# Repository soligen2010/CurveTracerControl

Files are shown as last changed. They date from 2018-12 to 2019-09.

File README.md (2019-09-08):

# CurveTracerControl

 This program is intended to instrument the Curve Tracer design published by Mr. Carlson's Lab on Patreon.  The original MCL
 design is available only to Patreon subscribers.  This software is released Open Source but does not contain the original 
 MCL project information upon which it is built.  If you want to build this project, I suggest you join Mr. Carlson's Lab on 
 Patreon to get the original project that this program augments.

 This project adds the following functionality to the MCL Curve Tracer

 1) Frequency counter for the Sine Wave
 2) Peak sine wave voltage display
 3) Step generator with hi/lo voltage display

 The step generator uses an R2R ladder and is fed through a series of op amps.  A Potentiometer controls final amplitude 
 and an op amp inverts the steps so that negative steps can be used.  A switch selects resistors to limit output current 
 to 10, 100, or 1000 uA. See the schematic for more details.
 
 This program uses a 5 volt 16 MHz Arduino with an ATMEGA328P.  Use of any other hardware may require alterations to the code. 
 A crystal oscillator rather than a resonator is preferred for frequency counter accuracy.

 The frequency counter in this program is limited to low frequencies.  It works for frequencies up to ~1000 Hz, but will
 likely fail at 2000 Hz or before.  The tested frequency range is 30 to 1070 Hz.
 
 Requires the NewLiquidCrystal Library from https://github.com/fmalpartida/New-LiquidCrystal
 
 Copyright 2018 by Dennis Cabell
 KE8FZX

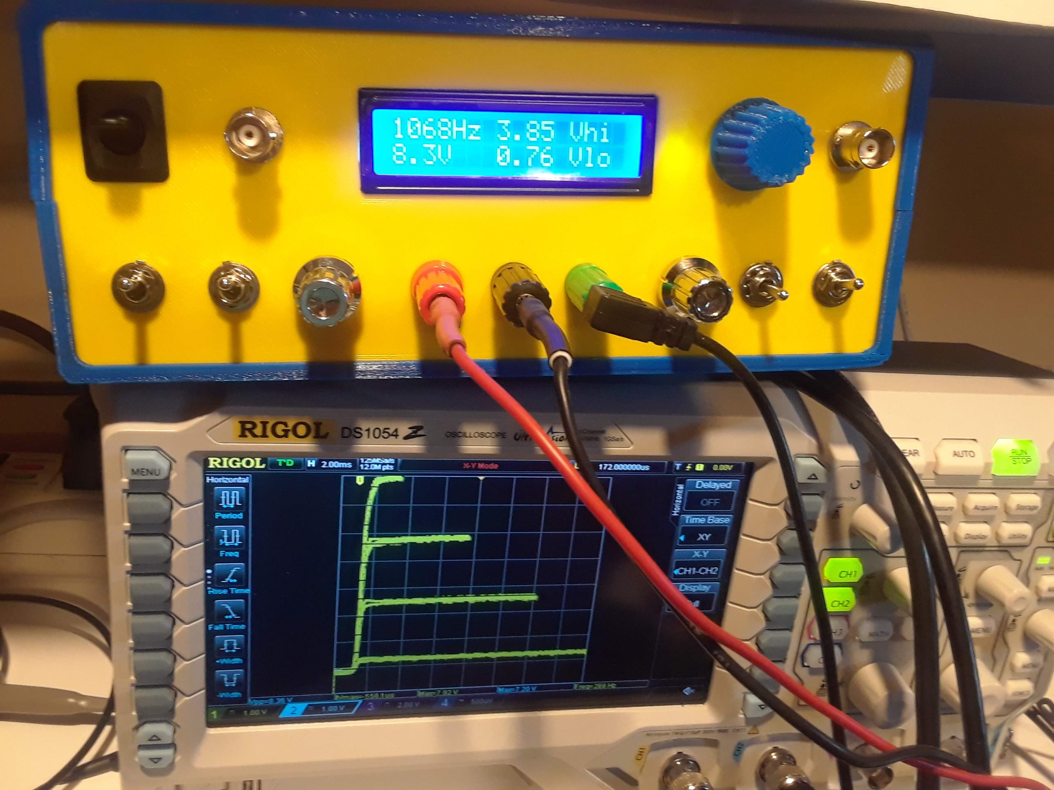
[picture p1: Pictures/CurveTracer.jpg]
Stepes Curves in Operation

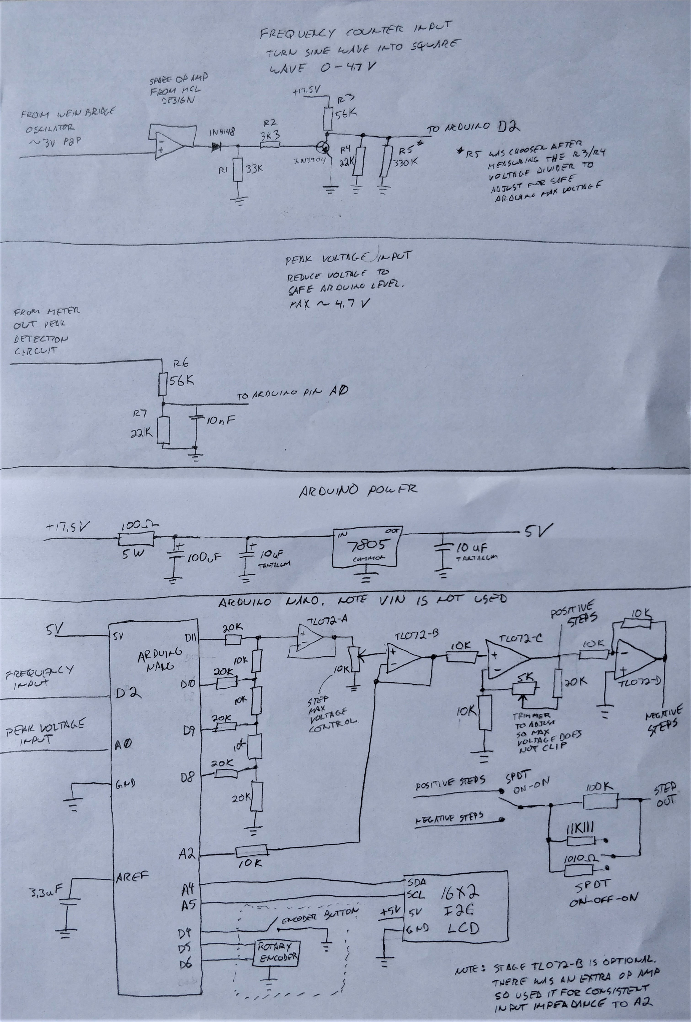
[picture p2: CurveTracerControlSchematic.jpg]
Schematic


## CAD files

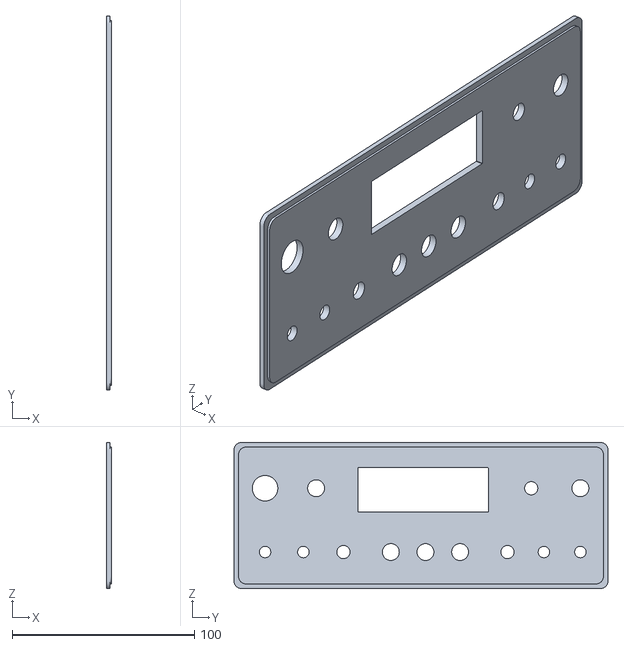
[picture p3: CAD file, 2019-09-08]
Case/CurveTracerFrontThick.stl
3.00 x 205.1 x 80.1

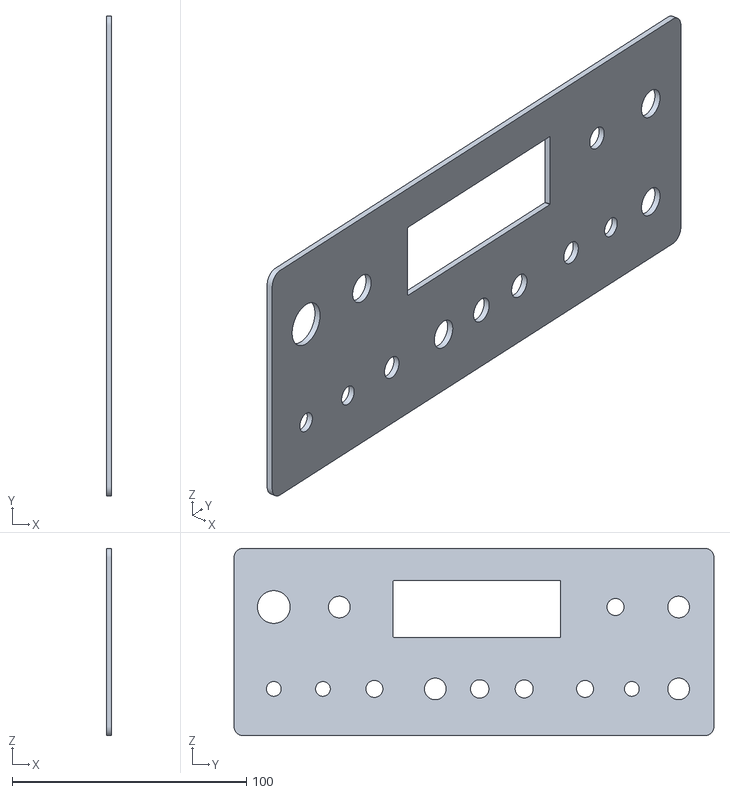
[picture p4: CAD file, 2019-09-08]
Case/CurveTracerFront.stl
2.00 x 205.1 x 80.1

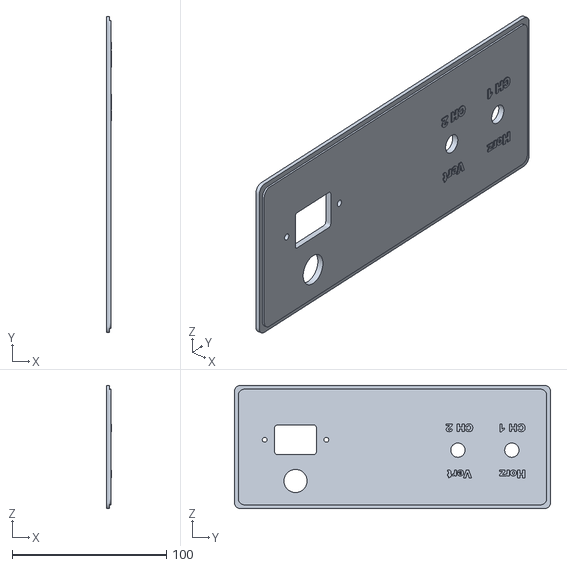
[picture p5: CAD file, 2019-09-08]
Case/CurveTracerBackThick.stl
3.50 x 205.1 x 80.1

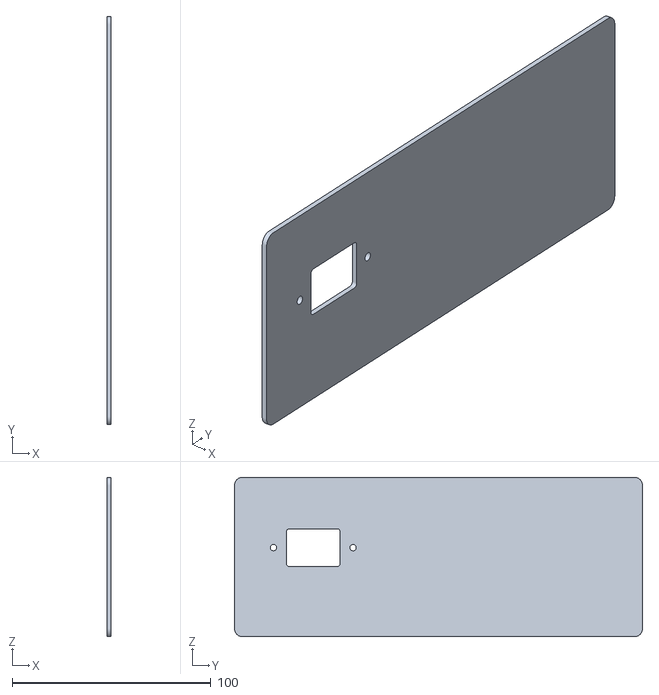
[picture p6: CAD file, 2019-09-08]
Case/CurveTracerBack.stl
2.00 x 205.1 x 80.1

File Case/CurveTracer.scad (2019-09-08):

/*//////////////////////////////////////////////////////////////////
              -    FB Aka Heartman/Hearty 2016     -                   
              -   http://heartygfx.blogspot.com    -                  
              -       OpenScad Parametric Box      -                     
              -         CC BY-NC 3.0 License       -                      
////////////////////////////////////////////////////////////////////                                                                                                             
12/02/2016 - Fixed minor bug 
28/02/2016 - Added holes ventilation option                    
09/03/2016 - Added PCB feet support, fixed the shell artefact on export mode. 
21/11/2017 by Richard Pillay - Added ability to have up to 4 PCBs

*/////////////////////////// - Info - //////////////////////////////

// All coordinates are starting as integrated circuit pins.
// From the top view :

//   CoordD           <---       CoordC
//                                 ^
//                                 ^
//                                 ^
//   CoordA           --->       CoordB


////////////////////////////////////////////////////////////////////


////////// - Paramètres de la boite - Box parameters - /////////////

/* [Box dimensions] */
// - Longueur - Length  
  Length        = 135;       
// - Largeur - Width
  Width         = 210;                     
// - Hauteur - Height  
  Height        = 85;  
// - Epaisseur - Wall thickness  
  Thick         = 2;//[2:5]  
// - Extra Panel Thickness - Double thickness (except edge) 
// usefull if panel contains a difficult plug
  ThickPanels   = 1;// 0 or 1
/* [Box options] */
// - Diamètre Coin arrondi - Filet diameter  
  Filet         = 4;//[0.1:12] 
// - lissage de l'arrondi - Filet smoothness  
  Resolution    = 50;//[1:100] 
// - Tolérance - Tolerance (Panel/rails gap)
  m             = 0.9;
// Pieds PCB - PCB feet (x4 for each) 
  PCB01Feet       = 0;// [0:No, 1:Yes]
  PCB02Feet       = 0;// [0:No, 1:Yes]
  PCB03Feet       = 0;// [0:No, 1:Yes]
  PCB04Feet       = 0;// [0:No, 1:Yes]
// - Decorations to ventilation holes
  Vent          = 1;// [0:No, 1:Yes]
// - Decoration-Holes width (in mm)
      Vent_width    = 1.5;   


  
/* [PCB_Feet] */
//All dimensions are from the center foot axis

PCB01Text = "PSU";
// - Coin bas gauche - Low left corner X position
PCB01PosX         = 10;
// - Coin bas gauche - Low left corner Y position
PCB01PosY         = 4;
// - Longueur PCB01 - PCB01 Length
PCB01Length       = 75;
// - Largeur PCB01 - PCB01 Width
PCB01Width        = 55;
// - Heuteur pied - Feet height
PCB01FootHeight      = 10;
// - Diamètre pied - Foot diameter
PCB01FootDiam         = 8;
// - Diamètre trou - Hole diameter
PCB01FootHole        = 2;  

PCB02Text = "Main";
PCB02PosX           = 10;
PCB02PosY           = 73;
PCB02Length         = 75;
PCB02Width          = 115;
PCB02FootHeight     = 10;
PCB02FootDiam      = 8;
PCB02FootHole        = 2;  
  
PCB03Text = "Regulator";
PCB03PosX           = 70;
PCB03PosY         = 110;
PCB03Length       = 50;
PCB03Width        = 55;
PCB03FootHeight      = 15;
PCB03FootDiam         = 10;
PCB03FootHole        = 3;  
  
PCB04Text = "FanMount";
PCB04PosX         = 25;
PCB04PosY         = 33;
PCB04Length       = 105;
PCB04Width        = 105;
    PCB04FootHeight      = 5;
PCB04FootDiam         = 12;
PCB04FootHole        = 5;  
  

/* [STL element to export] */
//Coque haut - Top shell
TShell          = 0;// [0:No, 1:Yes]
//Coque bas- Bottom shell
BShell          = 0;// [0:No, 1:Yes]
//Panneau avant - Front panel
FPanL           = 1;// [0:No, 1:Yes]
//Panneau arrière - Back panel  
BPanL           = 0;// [0:No, 1:Yes]


  
/* [Hidden] */
// - Couleur coque - Shell color  
Couleur1        = "Orange";       
// - Couleur panneaux - Panels color    
Couleur2        = "OrangeRed";    
// Thick X 2 - making decorations thicker if it is a vent to make sure they go through shell
Dec_Thick       = Vent ? Thick*2 : Thick; 
// - Depth decoration
Dec_size        = Vent ? Thick*2 : 0.8;





/////////// - Boitier générique bord arrondis - Generic rounded box - //////////

module RoundBox($a=Length, $b=Width, $c=Height){// Cube bords arrondis
                    $fn=Resolution;            
                    translate([0,Filet,Filet]){  
                    minkowski (){                                              
                        cube ([$a-(Length/2),$b-(2*Filet),$c-(2*Filet)], center = false);
                        rotate([0,90,0]){    
                        cylinder(r=Filet,h=Length/2, center = false);
                            } 
                        }
                    }
                }// End of RoundBox Module

      
////////////////////////////////// - Module Coque/Shell - //////////////////////////////////         

module Coque(){//Coque - Shell  
    Thick = Thick*2;  
    difference(){    
        difference(){//sides decoration
            union(){    
                     difference() {//soustraction de la forme centrale - Substraction Fileted box
                      
                        difference(){//soustraction cube median - Median cube slicer
                            union() {//union               
                            difference(){//Coque    
                                RoundBox();
                                translate([Thick/2,Thick/2,Thick/2]){     
                                        RoundBox($a=Length-Thick, $b=Width-Thick, $c=Height-Thick);
                                        }
                                        }//Fin diff Coque                            
                                difference(){//largeur Rails        
                                     translate([Thick+m,Thick/2,Thick/2]){// Rails
                                          RoundBox($a=Length-((2*Thick)+(2*m)), $b=Width-Thick, $c=Height-(Thick*2));
                                                          }//fin Rails
                                     translate([((Thick+m/2)*1.55),Thick/2,Thick/2+0.1]){ // +0.1 added to avoid the artefact
                                          RoundBox($a=Length-((Thick*3)+2*m), $b=Width-Thick, $c=Height-Thick);
                                                    }           
                                                }//Fin largeur Rails
                                    }//Fin union                                   
                               translate([-Thick,-Thick,Height/2]){// Cube à soustraire
                                    cube ([Length+100, Width+100, Height], center=false);
                                            }                                            
                                      }//fin soustraction cube median - End Median cube slicer
                               translate([-Thick/2,Thick,Thick]){// Forme de soustraction centrale 
                                    RoundBox($a=Length+Thick, $b=Width-Thick*2, $c=Height-Thick);       
                                    }                          
                                }                                          


                difference(){// wall fixation box legs
                    union(){
                        translate([3*Thick +5,Thick,Height/2]){
                            rotate([90,0,0]){
                                    $fn=6;
                                    cylinder(d=16,Thick/2);
                                    }   
                            }
                            
                       translate([Length-((3*Thick)+5),Thick,Height/2]){
                            rotate([90,0,0]){
                                    $fn=6;
                                    cylinder(d=16,Thick/2);
                                    }   
                            }

                        }
                            translate([4,Thick+Filet,Height/2-57]){   
                             rotate([45,0,0]){
                                   cube([Length,40,40]);    
                                  }
                           }
                           translate([0,-(Thick*1.46),Height/2]){
                                cube([Length,Thick*2,10]);
                           }
                    } //Fin fixation box legs
            }

        union(){// outbox sides decorations
            
            for(i=[0:Thick:Length/4]){
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

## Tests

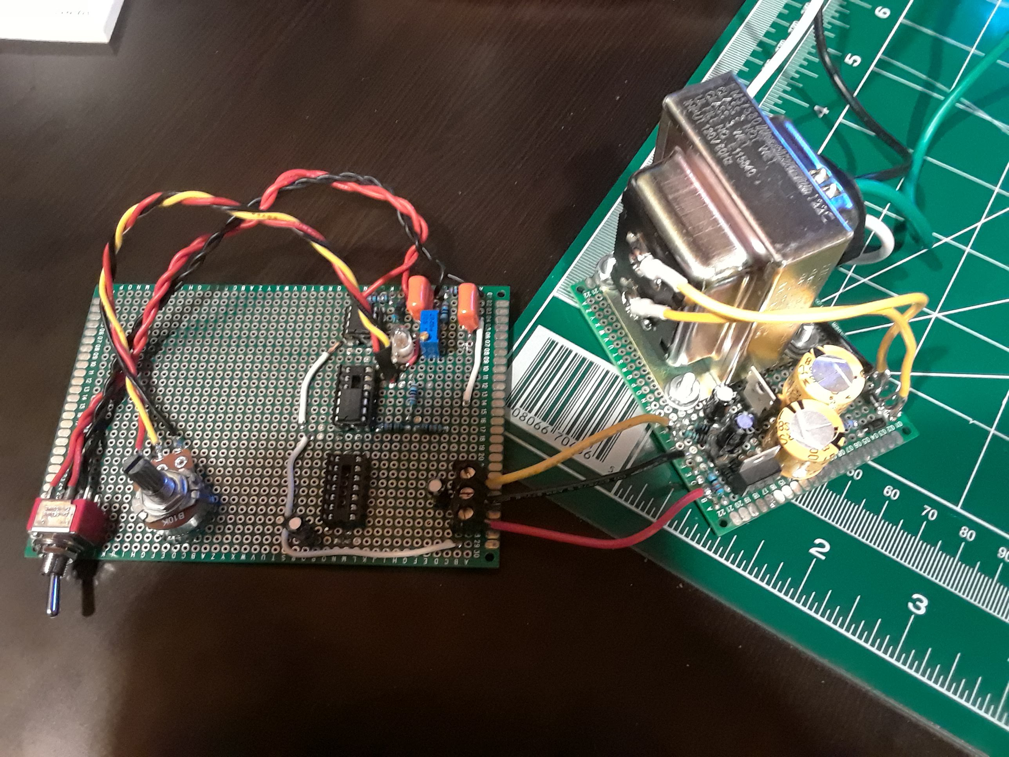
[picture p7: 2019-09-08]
Pictures/PartiallyComplete-Testing.jpg

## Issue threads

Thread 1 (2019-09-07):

Cannot upload the code

ovi4, 2019-09-07:
Hi, I am a contributor to Mr Carlson's Lab (on Patreon) and have access to all of his releases including the Curve Tracer schematic diagram and so on. Well I've already built the above Curve tracer and wanted to apply Denis Cambell's digital MOD  to it and already made a board with all the necessary (according to the given schematic but when tried to upload your code to my arduino uno board I get the following errors :

CurveTracerControl:92:15: error: expected primary-expression before 'encoder2'
 RotaryEncoder encoder2(ENCODER_PINB, ENCODER_PINA);

               ^
C:\Users\ovvid\Desktop\MCL PROJECTS\Curve Tracer\CurveTracerControl-MOD\CurveTracerControl-master\CurveTracerControl\CurveTracerControl.ino: In function 'void setup()':

CurveTracerControl:143:57: error: 'FreqCount' was not declared in this scope

   attachInterrupt(digitalPinToInterrupt(FREQ_COUNT_PIN),FreqCount,FALLING);
                                             
CurveTracerControl:145:3: error: 'encoder2' was not declared in this scope
   encoder2.setPosition(0);

   ^
CurveTracerControl:159:15: error: 'SetupTimer1' was not declared in this scope
   SetupTimer1();

               ^
C:\Users\ovvid\Desktop\MCL PROJECTS\Curve Tracer\CurveTracerControl-MOD\CurveTracerControl-master\CurveTracerControl\CurveTracerControl.ino: In function 'void FreqCount()':

CurveTracerControl:194:78: error: 'GenerateStep' was not declared in this scope
     int stepCount = GenerateStep (stepIndex, stepOutputActive, probeFreqError);

                                                                              ^
CurveTracerControl:195:38: error: 'ReadVoltages' was not declared in this scope
     ReadVoltages(stepIndex, stepCount);

                                      ^
C:\Users\ovvid\Desktop\MCL PROJECTS\Curve Tracer\CurveTracerControl-MOD\CurveTracerControl-master\CurveTracerControl\CurveTracerControl.ino: In function 'void loop()':

CurveTracerControl:240:45: error: 'DisplayProbeFrequency' was not declared in this scope
     probeFreqError = !DisplayProbeFrequency();

                                             ^
CurveTracerControl:242:28: error: 'DisplayProbeMaxVoltage' was not declared in this scope
     DisplayProbeMaxVoltage();

                            ^
CurveTracerControl:243:71: error: 'DisplayStepVoltage' was not declared in this scope
     DisplayStepVoltage(stepIndex, stepOutputActive, stepIndexdisplayOn);

                                                                       ^
CurveTracerControl:251:61: error: 'getStepIndex' was not declared in this scope
     stepIndex = getStepIndex(stepOutputActive, prevStepIndex);

                                                             ^
CurveTracerControl:259:80: error: 'GenerateStep' was not declared in this scope
       int stepCount = GenerateStep (stepIndex, stepOutputActive, probeFreqError);

                                                                                ^
CurveTracerControl:260:40: error: 'ReadVoltages' was not declared in this scope
      ReadVoltages(stepIndex, stepCount);

                                        ^
C:\Users\ovvid\Desktop\MCL PROJECTS\Curve Tracer\CurveTracerControl-MOD\CurveTracerControl-master\CurveTracerControl\CurveTracerControl.ino: In function 'int getStepIndex(bool, int)':

CurveTracerControl:300:27: error: 'encoder2' was not declared in this scope
     int encoderPosition = encoder2.getPosition();

                           ^
CurveTracerControl:318:5: error: 'encoder2' was not declared in this scope
     encoder2.setPosition(stepIndex);

     ^
C:\Users\ovvid\Desktop\MCL PROJECTS\Curve Tracer\CurveTracerControl-MOD\CurveTracerControl-master\CurveTracerControl\CurveTracerControl.ino: In function 'void __vector_5()':

CurveTracerControl:408:3: error: 'encoder2' was not declared in this scope
   encoder2.tick(); // just call tick() to check the state.

   ^
exit status 1
expected primary-expression before 'encoder2'

Is this a complete and verified (as working) code or is just a proof of concept and that it still needs a lot of work done to it ????
Also,  LiquidCristal_I2C.h library seems to be  more than 1 version of it with the same name and do not know what to choose.  I know from the past experience that loading the wrong type of arduino library can in fact give you errors and prevent you from uploading the code so maybe this is where it goes wrong.   Please note that I'm using an LCD 16x2  that has a little I2C board attached at the back with the chip marked as :  PCF8574T

Any help is much appreciated

PS:  please note that when it comes to coding a am a complete newbie. Well, I loaded a fair number of codes on my various personal projects (but they were always coded by others not myself)
Kind Regards

soligen2010, 2019-09-07:
First, just let me say that posing on the Carlson forum saying I had many coding errors is very obnoxious, and only a couple hours after this original github post - not even long enough for me to respond here.  I take pride in my coding and don't appreciate posts like that in a public forum.

This is a fully functional and tested project, but it is not a beginner project.  It expects that you know how to use Arduinos.

Looks to me that you either don't have Arduino installed correctly, did not download all the required files for the project, and/or don't have all the needed libraries installed.

You will need to install the NewLiquidCrystalLibrary from https://github.com/fmalpartida/New-LiquidCrystal

Once you get it to compile. I will caution you that not all I2C LCD displays are the same so you may need to change the I2C LCD pin assignments/ I2C address for the hardware you have.  You can google about this and find some likely combinations of pin assignments to try.

I'll just suggest that you learn Arduino on some simple things first.  There are lots of beginner Arduino tutorials out there.

soligen2010, 2019-09-07:
I updated the Readme with the required LCD library.

ovi4, 2019-09-07:
Hello there  and Thank You very much for the unexpected swift response. Didn't mean to offend you at all.  All I meant was that I'm getting errors on my IDE while trying to upload the code but didn't mean that your code was wrong at all. But because it turned out that way (the wording I used was not appropriate. My bad) I must apologise to you.  Further on, the post over there has now vanished.

 At first I've tryed to find your original Patreon post and I've spent a great deal of time trying  in hope to shed some light to my issue (before attempting to post)  but with no avail so I thought  well, it has been a number of months since that post and, people might sometimes erase their posts and that the whole idea has now been forgotten so I decided to post a message. On the other hand  I couldn't possibly know that on here you are the same person as there because of the soligen2010 name.
 So, I automatically assumed that Dennis Cabell of Patreon asked someone with coding experience ( namely soligen2010 of GitHub ) to help with the coding part  and that is the very reason I've posted there as well as here thinking that you are two different people and I will eventually get an answer from one or the other.

 I must thank you  for the great MOD idea and that you've kindly made it available and for the link regarding the right kind of LiquidCrystal_I2C library.  I went and tried it and : BINGO!  that was the problem  (as predicted) and I now  have a functioning code. I've loaded it on my arduino uno testing board just to verify that my LCD was up for the job and yes the address was 0x27 and of course I've changed the code accordingly.

I've made a separate (small size SMD style)  board to better fit in my ''teeny tiny''  TRIO CO-1303A scope that I've modified as the Curve Tracer. the board is still work in progress while waiting for some parts to arrive.

I have a few question regarding your schematic (if you don't mind) please :
1. the SPDT switch that handles the pos. and neg. steps, is  ON-OFF-ON (3 pin) type as well or ?
2. Where do i connect Step Out ?  @ pin 10 (TL074) on the MCL's Curve Tracer board  or?
3. When adapting your MOD what do I need to modify on MCL's Curve tracer original board aside from using the spare OP amp. as the sine/square wave frequency counter input stage?

Once I have it up and running I'll do some tests with it I will let you know of the result

Once again, your guidance and effort is very much appreciated

Kind regards.

soligen2010, 2019-09-07:
I am glad it is compiling for you now.  to your questions:

1) yes on off on
2) I don't know what pin 10 you are referring to (I used TL072, which only has 8 pins.)  At any rate, Step Out is the output of the step generator, which I sent to a banana jack.  It doesn't go to anything on the MCL circuit.
3) You don't need to change anything - just connect this to the proper places.  I didn't use his printed circuit board, I used perf board to make it.  be sure the check voltages and adjust R5 as needed before connecting to the Arduino so you don't fry the pin. It would be good to validate R6/R7 as well to be sure that max voltage is not too high.

What is in the project is the display of the freq & voltage, and the addition of a step generator.  Controls of the original MCL circuit is unchanged.

Another mod that I did (not shown here) is I added a switch to swap in different resistors and/or capacitors so my oscillator runs at either 1000ish or 30ish  Hz.  I don't have any documentation for this other mod (Others did the same thing before me), but I think you should be able to figure this out.

soligen2010, 2019-09-07:
correction on question 1.  It is a SPDT ON-ON (only 2 positions)

ovi4, 2019-09-08:
Tnx. very much for your kind help. I can now go ahead and close the issue on here.

Kind regards

Closed 2019-09-08.

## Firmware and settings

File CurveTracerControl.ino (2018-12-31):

/*
 Copyright 2018 by Dennis Cabell
 KE8FZX

 This program is intended to instrument the Curve Tracer design published by Mr. Carlson's Lab on Patreon.  The original MCL
 design is available only to Patreon subscribers.  This software is released Open Source but does not contain the original 
 MCL project information upon which it is built.  If you want to build this project, I suggest you join Mr. Carlson's Lab on 
 Patreon to get the original project that this program augments.

 This project adds the following functionality to the MCL Curve Tracer

 1) Frequency counter for the Sine Wave
 2) Peak sine wave voltage display
 3) Step generator with hi/lo voltage display

 The step generator uses an R2R ladder and is fed through a series of op amps.  A Potentiometer controls final amplitude 
 and an op amp inverts the steps so that negative steps can be used.  A switch selects resistors to limit output current 
 to 10, 100, or 1000 uA. See the schematic for more details.
 
 This program uses a 5 volt 16 MHz Arduino with an ATMEGA328P.  Use of any other hardware may require alterations to the code. 
 A crystal oscillator rather than a resonator is preferred for frequency counter accuracy.

 The frequency counter in this program is limited to low frequencies.  It works for frequencies up to ~1000 Hz, but will
 likely fail at 2000 Hz or before.  The tested frequency range is 30 to 1070 Hz.
 
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
 Code obtained from other authors are attributed in the files that contain their code.
 */

#include "RotaryEncoder.h"
#include "QuickStats.h"
#include <LiquidCrystal_I2C.h>

#define FREQ_SCALE_CAL   (float)1.0     // Multiplier to correct frequency
#define FREQ_OFFSET_CAL  (float)0.0     // Multiplier to correct frequency

#define PROBE_SCALE_CAL  (float)3.60    // Multiplier to read correct voltsge.  Modify to calibrate
#define PROBE_OFFSET_CAL (float)0.05    // +/- Offset to adjust, the same offset applies to all frequencies

#define STEP_SCALE_CAL   (float)3.242   // Multiplier to read correct voltsge.  Modify to calibrate
#define STEP_OFFSET_CAL  (float)0.014   // +/- Offset to adjust for proper zero volt reading

#define STEP_CYCLES         1           // how may probe cycles should pass for each step

#define STEP_COUNT_DISPLAY_DURATION 110 // How long to display the step count when it changes, before going back to high voltage display.  No specific units - higher is longer.

#define ENCODER_PINA        5           // Reverse pins A & B if the encoder movement is backwards
#define ENCODER_PINB        6
#define ENCODER_BTN         4

#define FREQ_COUNT_PIN      2
#define PROBE_VOLTAGE_PIN   A0
#define STEP_VOLTAGE_PIN    A2

#define MAX_TIMER_OVERFLOWS 32           // Will cause error display if probe frequnecy drops to about 1 Hz
#define HERTZ_SAMPLES       25           // How many samples of the frequency to use for the display.  The Mode of these is used.  Try increasing if display jitters.
#define VOLTAGE_SAMPLES     5            // How many samples of voltages to use for the display.  The Average of these is used.  Try increasing if display jitters, decrease if voltage display lags.
#define ADC_VOLTAGE_REF     5.021
                                         // 4 bit output to an R2R ladder
                                         // Don't change these.  These must be the first 4 pins of PORTB for the code to function properly
#define R2R_BIT1_PIN        8            // Low order bit - closest to the ground side
#define R2R_BIT2_PIN        9
#define R2R_BIT3_PIN        10
#define R2R_BIT4_PIN        11           // High order bit

// Note: These LCD I2C values may vary.  There are multiple versions of the I2C LCD boards.
// that use different address and pin assignments.  These worked for me but your hardware may differ and require changes.
#define LCD_I2C_ADDR        0x3F
//#define LCD_I2C_ADDR      0x27
#define I2C_EN_PIN          2
#define I2C_RW_PIN          1
#define I2C_RS_PIN          0
#define I2C_D4_PIN          4
#define I2C_D5_PIN          5
#define I2C_D6_PIN          6
#define I2C_D7_PIN          7
#define I2C_BL_PIN          3   //Back light
#define I2C_BACKLIGHT_POLARITY  POSITIVE

QuickStats stats;

LiquidCrystal_I2C lcd(LCD_I2C_ADDR,   // Set the LCD I2C address
                      I2C_EN_PIN,
                      I2C_RW_PIN,
                      I2C_RS_PIN,
                      I2C_D4_PIN,
                      I2C_D5_PIN,
                      I2C_D6_PIN,
                      I2C_D7_PIN,
                      I2C_BL_PIN,
                      I2C_BACKLIGHT_POLARITY);  

RotaryEncoder encoder2(ENCODER_PINB, ENCODER_PINA); 

volatile unsigned long freqInterruptTime1 = 0xFFFFFFFF;  
volatile int timerOverflows = 0;
volatile float highStepVoltage[VOLTAGE_SAMPLES] = {0};
volatile float lowStepVoltage[VOLTAGE_SAMPLES] = {0};
volatile float maxProbeVoltage[VOLTAGE_SAMPLES] = {0};
volatile bool probeFreqError = false;


volatile int stepIndex = 0;
volatile bool stepOutputActive = false;    

#define NUM_STEP_PROFILES 7

const byte stepProgression[NUM_STEP_PROFILES][16] = { // position 0 is the number of steps
                                {1,  15,  0,  0,  0,  0,  0,  0,  0,  0,  0,  0,  0,  0,  0,  0},  // one step always max voltage
                                {2,  15,  7,  0,  0,  0,  0,  0,  0,  0,  0,  0,  0,  0,  0,  0},  // two steps alternate max and half voltage
                                {3,  15,  8,  2,  0,  0,  0,  0,  0,  0,  0,  0,  0,  0,  0,  0},  // 3 steps
                                {4,  15, 11,  7,  3,  0,  0,  0,  0,  0,  0,  0,  0,  0,  0,  0},  // 4 steps
                                {5,  15, 12,  9,  6,  3,  0,  0,  0,  0,  0,  0,  0,  0,  0,  0},  // 5 steps
                                {8,  15, 13, 11,  9,  7,  5,  3,  1,  0,  0,  0,  0,  0,  0,  0},  // 8 steps
                                {15, 15, 14, 13, 12, 11, 10,  9,  8,  7,  6,  5,  4,  3,  2,  1}   // 15 steps
                              };

void setup()
{
  lcd.begin(16, 2);
  lcd.clear();
  lcd.setCursor(0, 0);lcd.print(F("  Curve Tracer"));

  pinMode(PROBE_VOLTAGE_PIN,INPUT);
  pinMode(STEP_VOLTAGE_PIN,INPUT);
  pinMode(FREQ_COUNT_PIN,INPUT);
  pinMode(ENCODER_PINA, INPUT_PULLUP);
  pinMode(ENCODER_PINB, INPUT_PULLUP);
  pinMode(ENCODER_BTN, INPUT_PULLUP);

  digitalWrite(R2R_BIT1_PIN,LOW);
  digitalWrite(R2R_BIT2_PIN,LOW);
  digitalWrite(R2R_BIT3_PIN,LOW);
  digitalWrite(R2R_BIT4_PIN,LOW);

  pinMode(R2R_BIT1_PIN,OUTPUT);
  pinMode(R2R_BIT2_PIN,OUTPUT);
  pinMode(R2R_BIT3_PIN,OUTPUT);
  pinMode(R2R_BIT4_PIN,OUTPUT);
  
  Serial.begin(57600);
  Serial.println("Starting Curve Tracer Control"); 

  attachInterrupt(digitalPinToInterrupt(FREQ_COUNT_PIN),FreqCount,FALLING);

  encoder2.setPosition(0);

  PCICR |= (1 << PCIE2);    // This enables Pin Change Interrupt 2 that covers Port D - needed for encoder
  PCMSK2 |= (1 << PCINT21) | (1 << PCINT22);  // This enables the interrupt for pin 5 and 6 of Port D - needed for encoder

  delay(2000);
  lcd.clear();
  
  // Disable timer0 interrupt.  millis(), micros() and dealy() won't function aftger this, but this way timer0 interrupts
  // will not affect timer1, which is used for frequency counting.  All other timing in the sketch is based
  // on counting the cycles for the probe frequency, which is calculated using timer1.
  // and the FreqCount interrupt routine
  TIMSK0 &= ~_BV(TOIE0);

  SetupTimer1();
}

void SetupTimer1() {
  noInterrupts();
  TCCR1A = 0;// set entire TCCR1A register to 0
  TCCR1B = 0;// same for TCCR1B
  TCNT1  = 0;// initialize counter value to 0

  TIMSK1 |= _BV(TOIE1);// enable overflow interrupt

  TCCR1B |= _BV(CS11); // set prescaler to 1.  

  interrupts();
}

void FreqCount() {
  static byte cycleCount = 0;
  byte extraOverFlow = 0;
  // stop counter breifly while we check everything
  TCCR1B &= ~(_BV(CS10) | _BV(CS11) | _BV(CS12)); 
  if ((TIFR1 & bit (TOV1)) && freqInterruptTime1 < 1024) {  // if an overflow is pending, we want to count it
    extraOverFlow++;
  }  
  freqInterruptTime1 = TCNT1;
  TCNT1  = 0;// initialize counter value to 0  
  TCCR1B |= _BV(CS11); // re-enable timer set prescaler to 8.  Resolution 0.5 uS
  #define TICKS_TIMER_WAS_TURNED_OFF 4  // add to compensate for the timer being off breifly.  This wasnt measured, just a guess 

  freqInterruptTime1 += (timerOverflows + extraOverFlow) * 0xFFFF + TICKS_TIMER_WAS_TURNED_OFF; 
  timerOverflows = (extraOverFlow == 1) ? -1 : 0; // of an overflow is pending, compensate by setting to -1 so overflow interrupts will set it to 0
  
  cycleCount++;

  if (cycleCount % STEP_CYCLES == 0 || probeFreqError) {
    int stepCount = GenerateStep (stepIndex, stepOutputActive, probeFreqError);
    ReadVoltages(stepIndex, stepCount);
  }
}

ISR(TIMER1_OVF_vect) {
  timerOverflows++;
  timerOverflows = (timerOverflows > MAX_TIMER_OVERFLOWS) ? MAX_TIMER_OVERFLOWS: timerOverflows;  // too many overflows is a frequency error so hold same value
}

bool checkButton(bool _stepsActive) {
  bool stepsActive = _stepsActive;
  static bool prevStepsActive = !stepsActive;
  static bool buttonDown = false;
  static byte PrevButtonState = HIGH;
  
  byte buttonState = digitalRead(ENCODER_BTN);

  if ((buttonState == HIGH) && buttonDown)   {    // make sure button was down at leasst 1 full cycle before registering click
    stepsActive = !stepsActive;
    buttonDown = false;    
  } 
  if ((buttonState == LOW) && PrevButtonState == LOW) {
    buttonDown = true;
  }
  PrevButtonState = buttonState;
  
  if (prevStepsActive != stepsActive) {
    if (stepsActive) {
      lcd.setCursor(7, 0);lcd.print("         ");  
    } else {
      lcd.setCursor(7, 0);lcd.print("Steps Off");
    }
    prevStepsActive = stepsActive;     
  }
  return stepsActive;
}

void loop()
{
  static bool prevStepOutputActive = false;    
  static unsigned int stepDisplayCountdown = 0;
  static int prevStepIndex = 0;
  static bool stepIndexdisplayOn = false;

  while(1==1) {
    probeFreqError = !DisplayProbeFrequency();
    
    DisplayProbeMaxVoltage();
    DisplayStepVoltage(stepIndex, stepOutputActive, stepIndexdisplayOn); 
    
    stepOutputActive = checkButton(stepOutputActive);
    if (prevStepOutputActive != stepOutputActive) {
      prevStepIndex = -1;  // Set to invalid value so it looks like a step change to step display triggers
      //encoder2.setPosition(prevStepIndex);
    }

    stepIndex = getStepIndex(stepOutputActive, prevStepIndex);  
    if (prevStepIndex !=  stepIndex) {
       stepDisplayCountdown = STEP_COUNT_DISPLAY_DURATION;
       stepIndexdisplayOn = true;
       prevStepIndex = stepIndex;
       prevStepOutputActive = stepOutputActive;
    }
    if (probeFreqError) {  //if no input freqeuncey do this so displays are updated and step voltage turned off
      int stepCount = GenerateStep (stepIndex, stepOutputActive, probeFreqError);
      ReadVoltages(stepIndex, stepCount); 
    }
    if (stepIndexdisplayOn && stepDisplayCountdown > 0) {
      stepDisplayCountdown--;
    } else {
      stepIndexdisplayOn = false;
    }
  }
}

bool DisplayProbeFrequency(){
  #define HERTZ_SAMPLES 25
  static float hertzHistory[HERTZ_SAMPLES] = {0};
  static long prevHertz = -1;
  static long hertz = 0;
  float hertzFloat;
  hertzFloat = FREQ_SCALE_CAL * (float)1000000.0 / (float)(freqInterruptTime1)*2.0 + FREQ_OFFSET_CAL;
  hertzFloat = constrain(hertzFloat,0.0,9999.0);

  static int iHistory = 0;
  hertzHistory[iHistory] = round(hertzFloat);
  iHistory++;
  iHistory = (iHistory < HERTZ_SAMPLES) ? iHistory : 0;

  hertz = stats.mode(hertzHistory,HERTZ_SAMPLES,0.1);
  if (hertz != prevHertz) {
    prevHertz = hertz;
    lcd.setCursor(0,0);lcd.print("       ");
    lcd.setCursor(0,0);lcd.print(hertz);lcd.print("Hz");
    return true;
  }
  if (timerOverflows >= MAX_TIMER_OVERFLOWS || hertzFloat >= 9999.0 || hertz == 0 || hertz >= 9999 ) {
     lcd.setCursor(0,0);lcd.print("ERROR  ");
     return false;
  }  
}

int getStepIndex(bool stepsActive, int prevStepIndex) {
  static int stepIndex = 0;
  if (stepsActive) {
    int encoderPosition = encoder2.getPosition();
    if (encoderPosition != stepIndex || stepIndex != prevStepIndex) {
      //Serial.println(encoderPosition);
      stepIndex = constrain(encoderPosition,0,NUM_STEP_PROFILES-1);
      encoder2.setPosition(stepIndex);
      lcd.setCursor(7,0);
      if (stepProgression[stepIndex][0] == 1) {
        lcd.print("Single V ");        
      } else {
        lcd.print(stepProgression[stepIndex][0]);
        if (stepProgression[stepIndex][0] == 2) {
          lcd.print(" Step   ");    
        } else {
          lcd.print(" Steps  ");     
        }
      }
    }
  } else {
    encoder2.setPosition(stepIndex);
  }
  return stepIndex;
}

void DisplayStepVoltage(int stepIndex, bool stepsActive, bool stepIndexdisplayOn) {  
  if (stepsActive && !stepIndexdisplayOn && (stepProgression[stepIndex][0] != 1)) {
    // this is the max step voltage.  Don't overwrite step off message if steps are off. Dont overwrite single V message
    // also dont display until display time for step count expires
    lcd.setCursor(7,0);lcd.print(stats.average(highStepVoltage,VOLTAGE_SAMPLES),2);lcd.print(" Vhi ");
  } 
  if ((stepProgression[stepIndex][0] == 1) || !stepsActive) {
    lcd.setCursor(7,1);lcd.print(stats.average(highStepVoltage,VOLTAGE_SAMPLES),2);lcd.print(" V   ");     
  } else {   
    if (stepsActive && stepProgression[stepIndex][0] != 1) {
      // this is the min step voltage
      lcd.setCursor(7,1);lcd.print(stats.average(lowStepVoltage,VOLTAGE_SAMPLES),2);lcd.print(" Vlo ");
    }
  }
}

inline void ReadVoltages(int stepIndex, int stepCount) { 
  static byte passCount = 0;   //count passes so we can alternate if we read the setp voltage or probe voltage
  static float voltage = 0; 
  static bool checkStepVoltage = false;
  static byte probeVoltageIndex = 0;
  static byte highStepVoltageIndex = 0;
  static byte lowStepVoltageIndex = 0;

  // only check one voltage per step because analog read is slow, so figure out which to check
  // if the number of steps is <=2 then the prob voltage must alternate with the step/high low
  // otherwise read probe voltage during a middle step
  if (stepProgression[stepIndex][0] <= 2) {
    if (passCount++ % 2 == 0) {
      checkStepVoltage = true;
    } else {
      checkStepVoltage = false;
    }
  } else {
    if (stepCount == 1 || stepCount == stepProgression[stepIndex][0]) {
      checkStepVoltage = true;
    } else {
      checkStepVoltage = false;
    }
  }
  
  if (checkStepVoltage) {  
    if (stepCount == 1 || stepCount == stepProgression[stepIndex][0]) {
      voltage = analogRead(STEP_VOLTAGE_PIN);  // throw away first read after pin change for better accuracy
      voltage = analogRead(STEP_VOLTAGE_PIN); 
      voltage = (voltage * ADC_VOLTAGE_REF / 1024.0 * STEP_SCALE_CAL) + STEP_OFFSET_CAL;
      if (stepCount == 1) {
        highStepVoltage[highStepVoltageIndex++] = voltage;
        highStepVoltageIndex = (highStepVoltageIndex ==  VOLTAGE_SAMPLES) ? 0 : highStepVoltageIndex;      
      } 
      if (stepCount == stepProgression[stepIndex][0] || stepProgression[stepIndex][0] == 1) {
        lowStepVoltage[lowStepVoltageIndex++] = voltage;
        lowStepVoltageIndex = (lowStepVoltageIndex ==  VOLTAGE_SAMPLES) ? 0 : lowStepVoltageIndex;      
      } 
    }
  } else {
    voltage = analogRead(PROBE_VOLTAGE_PIN);  // throw away first read after pin change for better accuracy
    voltage = analogRead(PROBE_VOLTAGE_PIN); 
    maxProbeVoltage[probeVoltageIndex++] = (voltage * ADC_VOLTAGE_REF / 1024.0 * PROBE_SCALE_CAL) + PROBE_OFFSET_CAL;
    probeVoltageIndex = (probeVoltageIndex ==  VOLTAGE_SAMPLES) ? 0 : probeVoltageIndex;      
  }
}

void DisplayProbeMaxVoltage() {  
  lcd.setCursor(0,1);lcd.print(stats.average(maxProbeVoltage,VOLTAGE_SAMPLES),1);lcd.print("V ");
}

inline int GenerateStep (int stepIndex, bool stepsActive, bool probeFreqError) {
  static int stepCount = 1;
  stepCount++;
  stepCount = (stepCount > stepProgression[stepIndex][0]) ? 1 : stepCount;
  
  if (stepsActive && !probeFreqError) {
    // Set the R2R ladder bits on PORTB pins 8 9 10 11
    PORTB = (PORTB & 0xF0) | stepProgression[stepIndex][stepCount];
  } else {
    PORTB &= 0xF0; 
  }  
  return stepCount;
}

// The Interrupt Service Routine for Pin Change Interrupt 
// This routine will only be called on any signal change on encoder pins: exactly when we need to check.
// Encoder uses no cpu time if it is not changing, so other interrupt routins are only potentially affected while encoder is is being used
ISR(PCINT2_vect) {
  encoder2.tick(); // just call tick() to check the state.
}

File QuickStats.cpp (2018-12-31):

/* QuickStats.cpp - Library for quick descriptive statistics of an array samples[] of size m
* Created by David Dubins, January 10th, 2016.
* Released into the public domain.
* Requires Arduino 1.6.6 or greater.
* http://pb860.pbworks.com
*/
 
#include "Arduino.h"
#include "QuickStats.h"
#include <math.h>
 
QuickStats::QuickStats(){/*nothing to construct*/}
QuickStats::~QuickStats(){/*nothing to destruct*/}
 
float QuickStats::average(float samples[],int m)
{
float total1=0.0;
for(int i=0;i<m;i++){
total1=total1+samples[i];
}
return total1/(float)m;
}
 
float QuickStats::g_average(float samples[],int m)
{
float total1=0.0;
for(int i=0;i<m;i++){
total1=total1+log(samples[i]);
}
return exp(total1/(float)m);
}
 
float QuickStats::minimum(float samples[],int m)
{
float sorted[m]; //Define and initialize sorted array
for(int i=0;i<m;i++){
sorted[i]=samples[i];
}
bubbleSort(sorted,m); // Sort the values
return(sorted[0]); // first element is the minimum
}
 
float QuickStats::maximum(float samples[],int m)
{
float sorted[m]; //Define and initialize sorted array
for(int i=0;i<m;i++){
sorted[i]=samples[i];
}
bubbleSort(sorted,m); // Sort the values
return(sorted[m-1]); // last element is the maximum
}
 
float QuickStats::stdev(float samples[],int m)
{
float avg=0.0;
float total2=0.0;
avg=average(samples,m);
for(int i=0;i<m;i++){
total2 = total2 + pow(samples[i] - avg,2);
}
return sqrt(total2/((float)m-1.0));
}
 
float QuickStats::stderror(float samples[],int m)
{
float temp1=0.0;
temp1=stdev(samples,m);
return (temp1/sqrt((float)m));
}
 
float QuickStats::CV(float samples[],int m) //Coefficient of variation (%RSD, or relative stdev)
{
float avg=0.0;
float sd=0.0;
avg=average(samples,m);
sd=stdev(samples,m);
return 100.0*sd/avg;
}
 
void QuickStats::bubbleSort(float A[],int len)
{
unsigned long newn;
unsigned long n=len;
float temp=0.0;
do {
newn=1;
for(int p=1;p<len;p++){
if(A[p-1]>A[p]){
temp=A[p]; //swap places in array
A[p]=A[p-1];
A[p-1]=temp;
newn=p;
} //end if
} //end for
n=newn;
} while(n>1);
}
 
float QuickStats::fabs(float sample) // calculate absolute value
{
if(sample<0.f){
return -sample;
}else{
return sample;
}
}
 
float QuickStats::median(float samples[],int m) //calculate the median
{
//First bubble sort the values: https://en.wikipedia.org/wiki/Bubble_sort
float sorted[m]; //Define and initialize sorted array.
float temp=0.0; //Temporary float for swapping elements
/*Serial.println("Before:");
for(int j=0;j<m;j++){
Serial.println(samples[j]);
}*/
for(int i=0;i<m;i++){
sorted[i]=samples[i];
}
bubbleSort(sorted,m); // Sort the values
/*Serial.println("After:");
for(int i=0;i<m;i++){
Serial.println(sorted[i]);
}*/
if (bitRead(m,0)==1) { //If the last bit of a number is 1, it's odd. This is equivalent to "TRUE". Also use if m%2!=0.
return sorted[m/2]; //If the number of data points is odd, return middle number.
} else {
return (sorted[(m/2)-1]+sorted[m/2])/2; //If the number of data points is even, return avg of the middle two numbers.
}
}
 
float QuickStats::mode(float samples[],int m,float epsilon) //calculate the mode.
//epsilon is the tolerance for two measurements to be equivalent.
{
//First bubble sort the values: https://en.wikipedia.org/wiki/Bubble_sort
float sorted[m]; //Temporary array to sort values.
float temp=0; //Temporary float for swapping elements
float unique[m]; //Temporary array to store unique values
int uniquect[m]; //Temporary array to store unique counts
/*Serial.println("Before:");
for(int i=0;i<m;i++){
Serial.println(samples[i]);
}*/
for(int i=0;i<m;i++){
sorted[i]=samples[i];
}
bubbleSort(sorted,m); // Sort the values
/*Serial.println("Sorted:");
for(int i=0;i<m;i++){
Serial.println(sorted[i]);
}*/
// Now count the number of times each unique number appears in the sorted array.
unique[0]=sorted[0];
uniquect[0]=1;
int p=0; // counter for # unique numbers
int maxp=0;
int maxidx=0;
for(int i=1;i<m;i++){
if(fabs(sorted[i]-sorted[p])<epsilon){
uniquect[p]++; //if same number again, add to count
if(uniquect[p]>maxp){
maxp=uniquect[p];
maxidx=p;
}
} else {
p++;
unique[p]=sorted[i];
uniquect[p]=1;
}
}
/*for(int i=0;i<p+1;i++){
Serial.println("Num: " + (String)unique[i] +" Count: " + (String)uniquect[i]);
}*/
if (maxp>1) {
return unique[maxidx]; //If there is more than one mode, return the lowest one.
} else {
return 0.0; //If there is no mode, return a zero.
}
}
 
float QuickStats::slope(float x[],float samples[],int m) //calculate the slope (dsamples/dx)
{
float xavg=average(x,m);
float yavg=average(samples,m);
float numerator = 0.0;
float denominator = 0.0;
for(int i=0;i<m;i++){
if(x[i]-xavg!=0.0){ // protect against dividing by zero
numerator = numerator + (x[i]-xavg)*(samples[i]-yavg);
denominator = denominator + ((x[i]-xavg)*(x[i]-xavg));
}
}
return numerator/denominator;
}
 
float QuickStats::intercept(float x[],float samples[],int m) //calculate the intercept (dsamples/dx)
{
float xavg=average(x,m);
float yavg=average(samples,m);
float beta=slope(x,samples,m);
return yavg-(beta*xavg);
}
 
void QuickStats::filternan(float samples[],int &m) //removes nan values and returns size of filtered matrix (destructive)
{
int duds=0; //keep track of #nans
int nums=0; //keep track of numbers
float filtered[m];
for(int i=0;i<m;i++){
if(isnan(samples[i])||isinf(samples[i])){
duds++; // found a nan
}else{
filtered[nums]=samples[i];
nums++; // found a number
}
}
for(int i=0;i<nums;i++){
samples[i]=filtered[i]; //overwrite sample matrix with filtered matrix
}
m=nums; //overwrite matrix size
}
 
void QuickStats::f_round(float samples[], int m, int p) //round float variable to a given # decimals, p
{
float precision=pow(10.0,p);
for(int i=0;i<m;i++){
samples[i]=round(samples[i]*precision)/precision;
}
}
 
//END OF FILE

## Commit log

2018-12-31 Fix Typos in comments
    [CurveTracerControl.ino]
2019-09-08 Added 3d printed case and pictures
    [CurveTracer.scad, CurveTracerBack.stl, CurveTracerBackThick.stl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]
2019-09-08 Updated Schematic
2019-09-08 Added schematic link

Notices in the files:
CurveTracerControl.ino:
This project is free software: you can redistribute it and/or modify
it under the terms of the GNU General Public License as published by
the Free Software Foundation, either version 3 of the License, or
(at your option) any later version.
